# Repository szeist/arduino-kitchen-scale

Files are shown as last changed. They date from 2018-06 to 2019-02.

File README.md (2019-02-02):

# Arduino Kitchen Scale with binary display

## Parts

1. 1x HX711 Load cell amplifier
3. 1x Straight bar load cell (2kg)
4. 1x Charlieplexed led array with 12 leds *(See schematics)*

## Requirements

1. [HX711_ADC](https://github.com/olkal/HX711_ADC) library
2. [CHPLX12](https://github.com/szeist/CHPLX12) library

## Calibrate

### 1. Upload calibration firmware

Define CALIBRATE_MODE in `firmware.ino`, complile and upload the firmware.

### 2. Put a known weightd item to the scale and use the serial interface for calibration

Connect to the serial port and use the following keys to adjust the measured weight:

| Key | Calibration Value |
| --- | --- |
| `h` | +1 |
| `H` | +10 |
| `l` | -1 |
| `L` | -10 |
| `t` | Tare |

### 3. Update the calibration factor

Update the `DEFAULT_CAL_FACTOR` in the `firmware.ino` with the new CalFactor value.

## Display

### Generate gerber files for production

1. Plot the PCB
    - Layers:
        - F.Cu
        - B.Cu
        - B.SilkS
        - F.SilkS
        - B.Mask
        - F.Mask
        - Edge.Cuts
    - Options:
        - [X] Use Protel filename extensions
        - [ ] Include extended attributes
        - [ ] Subtract soldermask from silkscreen

2. Generate drill file with the following options:
    - **Millimeters** as drill units
    - **Supress leading** zeros as zeros format
    - **PostScript** as drill map format

3. Rename all files with the `schematics/scripts/rename_gerber_files.sh` script

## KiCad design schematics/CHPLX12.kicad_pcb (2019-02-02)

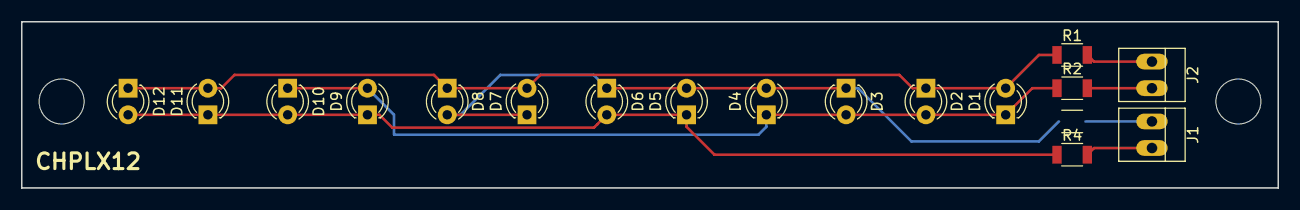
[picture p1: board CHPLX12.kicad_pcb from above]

Board: 2 copper layers, 120.0 x 15.9 mm, 18 parts (0 on the bottom side), 8 nets.

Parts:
D1, D2, D3, D4, D5, D6, D7, D8, D9, D10, D11, D12: LED; LED_D3.0mm
J1, J2: PINHEAD1-2
R1, R2, R3, R4: 220; R_1206

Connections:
unnamed: D1.1, D2.2, D3.2, D4.1, D9.2, D10.1, R2.1
unnamed: D1.2, D2.1, D7.2, D8.1, D11.2, D12.1, R1.1
unnamed: D3.1, D4.2, D5.2, D6.1, D7.1, D8.2, R3.1
unnamed: D5.1, D6.2, D9.1, D10.2, D11.1, D12.2, R4.1
PIN1: J2.1, R1.2
PIN2: J2.2, R2.2
PIN3: J1.1, R3.2
PIN4: J1.2, R4.2

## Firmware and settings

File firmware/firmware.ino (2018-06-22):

#include <Arduino.h>
#include <HX711_ADC.h>
#include <CHPLX12.h>

// #define CALIBRATE_MODE

#define STABILISING_TIME_MS 2000
#define DEFAULT_CAL_FACTOR 1030.0
#define REFRESH_TIME 250

float global_timer;
uint16_t global_display_value;

/*
  HX711 wiring (custom PINs)
  DT  = D3
  SCK = D4
*/
HX711_ADC LoadCell(3, 4);

/*
  CHPLC12 wiring
  PIN1 = D8
  PIN1 = D7
  PIN1 = D6
  PIN1 = D5
*/
CHPLX12 binaryDisplay(8, 7, 6, 5);


void setup() {
  binaryDisplay.clear();

  LoadCell.begin();
  LoadCell.start(STABILISING_TIME_MS);
  LoadCell.setCalFactor(DEFAULT_CAL_FACTOR);
  LoadCell.tare();

  #ifdef CALIBRATE_MODE
    Serial.begin(9600);
    Serial.println("Calibration mode initialized");
  #endif
}

void loop() {
  LoadCell.update();

  if (millis() > global_timer + REFRESH_TIME) {
    float weight = LoadCell.getData();

    #ifdef CALIBRATE_MODE
      float calFactor = LoadCell.getCalFactor();
      bool tareStatus = LoadCell.getTareStatus();
      calibrate_sendStatus(weight, calFactor, tareStatus);
      if (Serial.available() > 0) {
        char receivedCommand = Serial.read();
        calibrate_handleSerialCommand(receivedCommand);
      }
    #else
      global_display_value = getDisplayValue(weight);
    #endif
  
    global_timer = millis();
  }

  binaryDisplay.displayNumber(global_display_value);
}

static unsigned int getDisplayValue(float weight) {
  unsigned int value;

  if (weight < 0) {
    value = 0;
  } else if (weight > 4095) {
    value = 4095;
  } else {
    value = round(weight);
  }

  return value;
}

void calibrate_handleSerialCommand(char inByte) {
  float calDelta = 0;

  if (inByte == 'l') calDelta = -1.0;
  else if (inByte == 'L') calDelta = -10.0;
  else if (inByte == 'h') calDelta = 1.0;
  else if (inByte == 'H') calDelta = 10.0;
  else if (inByte == 't') LoadCell.tareNoDelay();

  if (calDelta != 't') {
    float calFactor = LoadCell.getCalFactor() + calDelta;
    LoadCell.setCalFactor(calFactor);
  }
}

void calibrate_sendStatus(float weight, float calFactor, bool tareStatus) {
  Serial.print("Weight: ");
  Serial.print(weight);
  Serial.print(" | CalFactor: ");
  Serial.println(calFactor);

  if (tareStatus) {
    Serial.println("Tare completed");
  }
}

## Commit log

2018-06-22 add display schematics
    [binary-display.kicad_pcb, binary-display.sch]
2018-06-22 extrace display driver
2019-02-02 add display pcb design with gerber files
    [CHPLX12.kicad_pcb, CHPLX12.sch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]
2019-02-02 remove unnecessary wire from pcb
    [CHPLX12.kicad_pcb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]
